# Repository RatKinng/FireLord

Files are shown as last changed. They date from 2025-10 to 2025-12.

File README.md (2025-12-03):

# FireLord Sensor Network Platform

FireLord is an open hardware reference for low-cost, peer-to-peer sensor meshes. The repository captures mechanical models, firmware helpers, PCB files, and planning artifacts produced during an Alaskan field concept so future teams can reuse or adapt the design.

---

## Intended Audience

- Municipal and resource agencies that need rapidly deployable sensor coverage.
- Community groups and educators building inexpensive environmental monitors.
- Integrators evaluating FireLord as a foundation for broader sensing programs.

---

## Repository Map

| Path | Contents |
| --- | --- |
| [`device-firmware/`](device-firmware/README.md) | Arduino-oriented helpers for sensor sampling and LoRa communication. |
| [`device-case/`](device-case/README.md) | 3D models, print notes, and assembly guidance for the field enclosure. |
| [`pcb-and-schematics/`](pcb-and-schematics/README.md) | KiCad project for the carrier board and custom footprints. |
| [`cosmos-firelord/`](cosmos-firelord/README.md) | OpenC3 COSMOS stack with the FireLord LoRa plugin, Docker compose, and bridge config for a base-station FireLord node over USB serial. |

---

## System Overview

1. **Field nodes** collect local sensor data, flag anomalies, and rebroadcast peer packets.  
2. **Base stations** are FireLord nodes flashed in base-station mode (no sensors, receive-only) that log every packet over USB serial and forward data when backhaul is available.  
3. **Optional cloud services** expose data to stakeholders or downstream tooling.

The mesh design keeps infrastructure light: any node can relay data, and a single active base station is sufficient.

---

## Quick Start

1. Review the operating targets below (range, duty cycle, enclosure limits) and adjust for your field conditions.  
2. Select components from the baseline bill of materials; plan on roughly $75 per node at 100-unit scale.  
3. Manufacture or print hardware following the subsystem READMEs.  
4. Load the firmware scaffold, confirm sensor and LoRa links, and tailor packet contents.  
5. Deploy nodes so each device reaches two peers or a base station, then validate end-to-end logging.

Use the risk guidance below while planning; the most common issues are supply delays, isolated nodes, and inadequate solar input.

---

## Operating Targets

- Peer-to-peer LoRa range: design for non-line-of-sight coverage of at least 500 m between nodes; verify in your terrain.  
- Reporting cadence: transmit sensor packets no less frequently than every 60 s unless power constraints dictate a longer interval.  
- Receive availability: keep the radio in a ready state to forward peer traffic continuously.  
- Data bandwidth: maintain ≥ 1.2 KB/s (9600 baud) for device-to-device links.  
- Power: average receive-ready draw ≤ 100 mW with duty-cycled heaters; energy storage provided by supercapacitors only.  
- Mechanical envelope: keep external dimensions within 200 mm per axis to fit the reference enclosure.  
- Environmental durability: target IP55 ingress protection and verified operation down to −30 °C for at least 30 min.  
- Radio spectrum: operate in the regional sub-GHz LoRa band (e.g., 902–928 MHz in North America) with a fixed-length header and byte-structured frame format.  
- Bill of materials: $75 per node is achievable at 100-unit quantities using the parts listed below.

---

## Deployment Notes

- **Topology**: Maintain overlapping coverage; document approved node spacing before field work.  
- **Placement**: Mount above snow or vegetation, shield cables from wildlife, and orient vents downward.  
- **Backhaul**: Configure the base station to cache indefinitely; cloud transfer is optional.  
- **Operations**: Schedule inspections ahead of seasonal activities (e.g., controlled burns or tourism peaks).

---

## Ground Operations (COSMOS)

- Use `cosmos-firelord/` to run OpenC3 COSMOS locally and view the `LORA` target. Update `.env` secrets before exposing ports beyond localhost.  
- Bridge a base-station FireLord node (USB serial) to COSMOS with the provided profile: `./openc3.sh cli bridge openc3-cosmos-lora/bridge.txt write_port_name=/dev/ttyACM0 baud_rate=115200 router_port=2950`. The plugin instance expects `host.docker.internal:2950`.  
- Base-station firmware emits `DATA <nodeId> <ver> <ts> <tempCx100> <humidity> <co2> <pressure> <voc> <smoke> <flags>` on every validated packet; COSMOS tooling can key off that stable line alongside the `[RX]` log. Nodes are TX-only; no COSMOS commands defined.  
- Container lifecycle: `./openc3.sh run` to start, `./openc3.sh stop` to halt; see `cosmos-firelord/README.md` for rebuild and reload steps.

---

## Hardware Snapshot

| Component | Key details | Mount style | Unit cost (USD, 2-unit qty) | Remarks |
| --- | --- | --- | --- | --- |
| [LoRa module (Reyax RYLR998)](https://www.digikey.com/en/products/detail/reyax/RYLR998/22078252) | 3.3 V P2P radio | Through-hole module | 16.90 | Ships on a carrier with 2.54 mm headers; can be socketed or wired directly without reflow. |
| [MCU (Seeeduino XIAO SAMD21)](https://www.digikey.com/en/products/detail/seeed-technology-co-ltd/102010328/11506471) | Arduino-compatible controller | Castellated SMD | 5.40 | Hand-solderable to the XIAO footprint; DIP adapters are available if you prefer header pins. |
| [CO₂/temp/humidity sensor (Sensirion SCD40)](https://www.digikey.com/en/products/detail/sensirion-ag/SCD40-D-R2/13684008) | I²C environmental sensing | LGA SMD | 17.95 | Use a breakout like the [SparkFun SEN-18360](https://www.sparkfun.com/products/18360) when avoiding reflow. |
| [CO sensor (MQ-7)](https://www.digikey.com/en/products/detail/olimex-ltd/SNS-MQ7/21662604) | Analog gas sensor | Through-hole | 5.65 | Duty-cycle the heater to save power. |
| [Pressure sensor (NXP MPL115A2)](https://www.digikey.com/en/products/detail/nxp-usa-inc/MPL115A2ST1/16538791) | I²C barometer | LGA SMD | 4.75 | Choose a breakout (Adafruit 992 or similar) if assembling without reflow. |
| [Smoke sensor (DFRobot SEN0570)](https://www.digikey.com/en/products/detail/dfrobot/SEN0570/24611153) | Analog particle indicator | Module w/2.54 mm header | 4.90 | Mount behind vent mesh. |
| [VOC sensor (DFRobot SEN0566)](https://www.digikey.com/en/products/detail/dfrobot/SEN0566/24611145) | Analog VOC indicator | Module w/2.54 mm header | 4.90 | Co-locate with smoke sensor. |
| [Supercapacitor (Tecate TPLH-2R7-800)](https://www.digikey.com/en/products/detail/tecate-group/TPLH-2R7-800PS35X71/21378858) | 2.7 V 800 F storage | Radial through-hole | 17.50 (each) | Use two in series with balancing. |
| [Base-station node (FireLord in BASE_STATION_MODE)](https://www.digikey.com/en/products/detail/seeed-technology-co-ltd/102010328/11506471) | USB-powered receive-only gateway | Onboard | 5.40 + radio | Same hardware as field nodes; flash with `BASE_STATION_MODE=true` and omit sensors. |
| [Solar panel (Seeed 1 W)](https://www.mouser.com/ProductDetail/Seeed-Studio/313070001) | 5 V nominal, 1 W | Leaded | 11.95 | Size array for local insolation. |
| [Connectors, cabling, misc.](https://www.amazon.com/100Pcs-Connector-Include-Female-Ph2-0mm/dp/B0DMW21LWS) | JST harnesses, fasteners | Through-hole / pre-crimped | ~10.00 | Include spare gaskets and glands. |

Estimated total: ≈ $75 per field node at 100-unit scale. Choosing breakout boards for the SMD-only sensors raises cost slightly but simplifies assembly when reflow is unavailable.

---

## Power Profile

- 283 mW: receive-ready state with high-draw sensors active.  
- 116 mW: duty-cycled average with smoke/VOC heaters at 5 % duty.  
- 600 mAh equivalent storage supports ~7 h at peak load and ~17 h at averaged load.

Adjust sampling cadence, heater duty cycles, or panel capacity to meet local endurance goals.

---

## Risk Summary

| Theme | Mitigation |
| --- | --- |
| Part delays | Order early, maintain alternates, record substitutions. |
| Node isolation | Pre-survey install sites, document minimum spacing, train field crews. |
| Power loss | Site panels in clear sun, inspect seasonally, log low-voltage events. |
| Sensor drift | Implement firmware sanity checks; schedule recalibration windows. |
| Base station downtime | Provide backup power and confirm local logging before field work. |

Document mitigations and revisit them seasonally to keep deployments stable.

---

## Extending the Platform

- Add routing intelligence, adaptive transmit power, or health beacons for larger meshes.  
- Integrate SMS, dashboard, or API publishing pipelines.  
- Incorporate soil probes, weather stations, or perimeter sensors.  
- Package sensor pods for quick swap service.  
- Expand packet signing or integrity checks for regulated deployments.

---

## Prototype Artifacts

- Work breakdowns and PERT charts outline the original build sequence.  
- Firmware helpers (`I2C_COMMS`, `UART_COMMS`) provide safe defaults for sensor and radio access.  
- Mechanical CAD documents enclosure iterations and tolerance tests.

Use these as reference when creating production-ready variants.

---

## System Characteristics

- **Operating profile**: LoRa P2P mesh at 915 MHz (example: SF7, 125 kHz BW, CR 4/5, 10 dBm) with receive-ready nodes and 60 s sampling. Packets are fixed-length (23 bytes payload + CRC32) with flag bits for outliers and a rolling CRC buffer to block duplicates.  
- **Performance targets**: ≥ 500 m NLOS hops, ≥ 1.2 KB/s link budget (9600 baud), IP55 enclosure, −30 °C for 30 min, and < 200 mm mechanical span. Power: 283 mW RX-ready with heaters on; ≈116 mW average at 5 % heater duty. 600 mAh-equivalent storage yields ~7 h peak or ~17 h average runtime. BOM ≈ $75 per node at 100-unit quantities.  
- **Radio and payload**: Example initialization uses `AT`, `AT+MODE=TEST`, `AT+TEST=RFCFG,…`, `AT+TEST=RXLRPKT`; `UART_COMMS::p2pTxHex` waits for `+TEST: TX DONE`. Payload layout mirrors `device-firmware/FireLordNode` suggestions (version, device ID, timestamp, temperature, humidity, CO₂, CO, pressure, smoke, VOC, flags, CRC32).  
- **Electronics**: KiCad carrier hosts a Seeeduino XIAO (I²C, UART, analog), Reyax/Wio-E5 radio, and connectors for SCD40, MPL115A2, MQ-7, smoke, and VOC sensors. Supercapacitor pads include balancing; test pads expose 3.3 V, ground, UART TX/RX, and reset. Footprints favor hand assembly; run ERC/DRC, then generate Gerbers and pick-and-place before fab.  
- **Firmware behavior**: Samples I²C sensors via `I2C_COMMS`, analog after heater warm-up, validates ranges, packages the frame, records CRC history, and transmits through `UART_COMMS`. Bench mode seeds data when sensors are absent. Power practices include MOSFET-controlled heaters, RTC/low-power sleep, and voltage checks to gate TX.  
- **Enclosure and assembly**: `device-case` contains Fusion 360, STEP, 3MF, and OpenSCAD sources. Print with PETG/ASA/PC, 0.2 mm layers, ≥ 3 perimeters, 20 % infill; gaskets in TPU or 2 mm silicone. Assembly sequence: seat gasket, mount PCB on M3 standoffs, route solar/antenna through glands with strain relief, close lid diagonally, add vent mesh. Use conformal coating and desiccant; vents should face down. Heat/flame resistance is not provided.  
- **Deployment and validation**: Maintain overlapping node coverage, mount above vegetation/snow, shield cables, and cache packets indefinitely at the base-station node on USB serial. Validation steps: pre/post I²C scans, `LoRaE5::ping()`, inspect TX/RX/FWD serial logs (including `DATA …`) for delivery, and record hop counts during field trials. Revisit risk mitigations seasonally (supply, isolation, power, sensor drift, base-station uptime).  
- **Extension paths**: OTA or signed updates, adaptive routing/TX power, cloud/API publishing, additional sensors (soil, weather, perimeter), antenna/housing variants, and SMA with controlled impedance for external antennas.

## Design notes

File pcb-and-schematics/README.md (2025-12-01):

# Electronics Design Guide

The KiCad project in this directory defines the sensor carrier board used by FireLord. It is suitable for small fabrication runs and straightforward to adapt for alternate sensors or power stages.

---

## Project Layout

```
Pressure_Sensor/
└── Pressure_Sensor_Board/
    ├── Pressure_Sensor_Board.kicad_pro
    ├── Pressure_Sensor_Board.kicad_sch
    ├── Pressure_Sensor_Board.kicad_pcb
    ├── PressureSensor.pretty/
    └── fp-lib-table
```

Open the `.kicad_pro` file in KiCad 7+. If footprints appear missing, point KiCad to the bundled `PressureSensor.pretty` library.

---

## Circuit Highlights

- Seeeduino XIAO header exposing I²C, UART, analog, and power rails.  
- JST or locking connectors for CO, smoke, VOC, and other sensor daughterboards.  
- SCD40 and MPL115A2 wired on a shared I²C bus with 400 kHz pull-ups.  
- Supercapacitor pads with balancing resistors and space for optional regulators.  
- Test pads for 3.3 V, ground, UART TX/RX, and reset.

Trace widths and component spacing were selected for easy hand assembly.

---

## Fabrication Workflow

1. Run ERC/DRC and resolve any violations.  
2. Generate Gerbers, drills, and pick-and-place files; archive each release (e.g., `fab/2025-03-RevA/`).  
3. Order 1.6 mm FR-4, 1 oz copper boards from your preferred supplier.  
4. Assemble SMD parts first, then supercapacitors and connectors.  
5. Verify I²C devices with the firmware scan and confirm LoRa UART signalling before enclosure install.

---

## Customization Notes

- Update footprints and BOM items when swapping sensors; confirm mechanical clearance against the enclosure model.  
- Replace the supercapacitor block with LiFePO₄ hardware if longer runtime is required.  
- Add extra headers for status LEDs, buttons, or expansion harnesses.  
- Introduce an SMA footprint with controlled impedance if you need external antennas.

Record every change with a new schematic and PCB revision.

---

## Footprint Library

`PressureSensor.pretty` contains enlarged pads for hand soldering. If you fork the design, duplicate the library and keep naming conventions (e.g., `FLD_SENSOR_*`) so scripts resolve correctly. Export 3D models as needed for enclosure fit checks.

---

## Additional Notes

- BOM reference: LoRa radio $16.90, Seeeduino $5.40, SCD40 $17.95, supercapacitors $17.50 each, remaining sensors $5–$10.  
- Environmental targets: IP55 enclosure, −30 °C survivability for 30 min, and a 200 mm maximum dimension to fit the printed housing.  
- Common risks: delayed component deliveries, insufficient node density, and inadequate solar exposure; plan mitigations during layout and procurement.

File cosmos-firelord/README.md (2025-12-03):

# FireLord COSMOS Stack

This folder packages a ready-to-run OpenC3 COSMOS instance for FireLord field testing. It mounts the FireLord LoRa plugin, exposes the COSMOS web UI locally, and includes a bridge profile for piping radio traffic from a base-station FireLord node (USB serial) into COSMOS tools.

## What's Here

- `compose.yaml` and `.env`: container stack and defaults pinned to OpenC3 6.9.2 in local mode. Update the secrets in `.env` before exposing beyond localhost.
- `openc3-cosmos-lora/`: plugin source plus the TCP bridge profile (`bridge.txt`) that relays a LoRa serial link into COSMOS.
- `plugins/DEFAULT/openc3-cosmos-lora/`: the packaged `openc3-cosmos-lora-1.0.0.gem` with an instance preconfigured for target `LORA` on `host.docker.internal:2950`.
- `openc3.sh` / `openc3.bat`: helper wrapper for running, stopping, and managing COSMOS containers.

## Quick Start (Local)

1) Install Docker with Compose and add your user to the Docker group (or run with sudo).  
2) From the repo root: `cd cosmos-firelord`  
3) Edit `.env` to rotate all placeholder passwords and adjust ports if 2900/2943 collide locally.  
4) Start COSMOS:  
   - macOS/Linux: `./openc3.sh run`  
   - Windows: `openc3.bat run`  
   Wait for the `openc3-init` container to finish, then open http://localhost:2900.

## Hook Up the Base-Station Node

The FireLord plugin expects a TCP feed on port `2950`. Use the included bridge profile to forward a FireLord device running `BASE_STATION_MODE=true` (receive-only, sensorless) into that port:

```bash
cd cosmos-firelord
./openc3.sh cli bridge openc3-cosmos-lora/bridge.txt \
  write_port_name=/dev/ttyACM0 \
  read_port_name=/dev/ttyACM0 \
  baud_rate=115200 \
  router_port=2950
```

- COSMOS “attempting to connect” here is only the TCP socket to this bridge, not RF link state. If you see it, the bridge is not reachable.
- Free the port first. `compose.yaml` currently maps `openc3-minio` to `127.0.0.1:2950`, which blocks the bridge. Comment that mapping or pick another port and update `plugin.txt`, `plugin_instance.json`, and `bridge.txt` to match.
- Run the bridge where the USB device is available. The helper command runs inside a container; on Windows/WSL it is often easier to run a host-side serial→TCP forwarder on the chosen port instead.

- Change `/dev/ttyACM0` to the COM/tty device for your base-station node.  
- Adjust `router_listen_address` if COSMOS is running on another host.  
- The plugin instance in `plugins/DEFAULT` points to `host.docker.internal:2950`, so the bridge must run on the same machine as Docker.

## Using the FireLord LORA Target

- Target name: `LORA` (configurable via `plugins/DEFAULT/openc3-cosmos-lora/plugin_instance.json`).  
- Interface: TCP client to the local bridge (port 2950).  
- Telemetry reflects the 23-byte FireLord sample payload (version, node ID, uptime seconds, temperature x100 C, humidity x100 %, CO2 ppm, pressure x10 hPa, VOC/SMOKE ADC counts, status flags, CRC32). The base-station firmware emits a `DATA …` line for every validated packet that can be parsed downstream; nodes are TX-only, so no commands are defined yet.  
- Screens/procedures live under `openc3-cosmos-lora/targets/LORA/` and will appear in COSMOS once the plugin is loaded.

## Updating the Plugin

1) Edit the plugin source under `openc3-cosmos-lora/` (e.g., add real telemetry items).  
2) Build a new gem: `./openc3.sh cli rake build VERSION=1.0.1` from inside `openc3-cosmos-lora/`.  
3) Replace the gem in `plugins/DEFAULT/openc3-cosmos-lora/` and update `plugin_instance.json` if the filename changes.  
4) Reload the plugin in COSMOS (Admin → Plugins) or via CLI:  
   `./openc3.sh cli load plugins/DEFAULT/openc3-cosmos-lora/openc3-cosmos-lora-1.0.1.gem DEFAULT plugins/DEFAULT/openc3-cosmos-lora/plugin_instance.json force`.

## Notes

- Keep the `.env` credentials private; they are mounted directly into containers.  
- The `plugins/DEFAULT` directory is bind-mounted and will be modified at runtime; commit only intentional changes.  
- For networks beyond localhost, enable TLS by swapping `openc3-traefik/traefik.yaml` for one of the SSL variants and providing certificates.

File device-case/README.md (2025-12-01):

# Device Enclosure Guide

This directory holds the enclosure CAD for the FireLord node. Models target desktop FDM printers and support IP55-style sealing.

---

## File Index

| File | Notes |
| --- | --- |
| `FireLordCase.f3d` | Fusion 360 source. |
| `FireLordCase.step` | Neutral CAD export. |
| `FireLordCase.3mf` | Full assembly print plate. |
| `FireLordCaseBody.*`, `FireLordCaseLid.*`, `FireLordCaseGasket.*` | Individual components. |
| `FireLordCaseMesh.*` | Vent cover for airflow. |
| `case.scad`, `size-tests.scad` | OpenSCAD parametric scripts and tolerance checks. |

---

## Print Defaults

- Material: PETG, ASA, PC, or other outdoor-tolerant material; PLA only for indoor pilots. Gasket should be TPU or other flexible filament.  
- Layer height: 0.2 mm (0.16 mm for smoother gasket lands).  
- Perimeters: ≥ 3 (for sufficient water-proofing).  
- Infill: 20 % grid/gyroid for the body; solid for the gasket supports.  
- Supports: Off for body/lid/gasket; trees for the mesh.  
- Orientation: Body upright, lid upside-down, mesh and gasket flat.

Run `size-tests.scad` before large batches.

---

## Assembly Steps

1. **Gasket** – Print in TPU or cut 2 mm silicone, then dry-fit the lid channel.  
2. **Electronics** – Mount the PCB on standoffs with stainless M3 hardware; align sensors with vent openings.  
3. **Cabling** – Route solar and antenna leads through side ports, sealing with glands or potting as required; strain-relief internal wiring.  
4. **Closure** – Seat the gasket, tighten lid screws diagonally, confirm even compression.  
5. **Finish** – Install the mesh cover and label the enclosure with device ID and install date.

---

## Environmental Notes

- **Cold**: Add insulating foam around supercapacitors and orient vents downward to shed ice.  
- **Moisture**: Apply conformal coating and include desiccant in humid regions.  
- **Wildlife**: Mount ≥ 3 m high where large animals are active; guard solar panels with metal frames.  
- **Heat or flame**: The case is not fire-rated—document safe-service guidelines for field teams.

---

## CAD Adjustments

- Modify `case.scad` for alternate sensor cut-outs or mounting features.  
- Extend the lid if an external antenna requires additional clearance.  
- Add hinged or quick-release hardware if frequent access is expected.

Track revisions alongside firmware changes to keep assemblies synchronized.

---

## Deployment Reminders

- Assemble indoors and transport with desiccant packs.  
- Use torque-limited drivers to prevent cracking.  
- Record install coordinates and photos.  
- Inspect critical sites before seasonal operations to clear vents and verify seals.

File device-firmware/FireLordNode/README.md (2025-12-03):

# Device Firmware Guide

The firmware runs on a Seeeduino XIAO SAMD21 (or comparable 3.3 V Arduino board) and drives the Reyax-class LoRa module plus the sensor suite. This outline assumes Arduino IDE or PlatformIO as the build tool.

---

## Inputs and Dependencies

- MCU: Seeeduino XIAO SAMD21 with hardware UART and I²C.  
- LoRa radio: Grove Wio-E5, Reyax RYLR998, or any AT-driven LoRa-E5 module on 3.3 V logic.  
- Sensors: SCD40 (I²C), MQ-7 (analog), MPL115A2 (I²C), MEMS smoke (analog), MEMS VOC (analog).  
- Host tooling: Arduino IDE or PlatformIO with Seeed SAMD board package.  
- Helpers: `I2C_COMMS`, `UART_COMMS`, and `SamplePacket.h`; optional `pseudo.cpp` shows an early loop.

---

## File Reference

| File | Purpose |
| --- | --- |
| `FireLordNode.ino` | Main sketch for the field node; samples sensors and forwards packets via LoRa-E5. |
| `I2C_COMMS.*` | Safe wrappers for register reads and raw bursts. |
| `UART_COMMS.*` | Stream helper with LoRa-E5 AT shortcuts. |
| `pseudo.cpp` | Example loop covering sampling, validation, and packet assembly. |

Import the sketch folder (`FireLordNode.ino`, helper headers, and sources) into Arduino IDE or PlatformIO as-is; avoid renaming the files because the build references them directly.

---

## Bring-Up Checklist

1. Install the “Seeed SAMD Boards” package in Arduino IDE (or PlatformIO equivalent).  
2. Create a project, add the helper headers, and include them in `setup()`.  
3. Wire sensors to SDA/SCL and analog inputs; connect the LoRa module to `Serial1`.  
4. Run an I²C scan and `LoRaE5::ping()` to confirm hardware connectivity.

---

## Sampling Pattern

Each node wakes every 30 s, samples local sensors, and packages readings into a fixed 23-byte payload plus a CRC32 footer. The CRC is stored in a small ring buffer so the node can recognise its own transmissions and recent relays. The high-level flow is:

1. Wake on a timer (e.g., 60 s).  
2. Read I²C sensors with `I2C::readFromReg`.  
3. Sample analog channels after heater warm-up.  
4. Validate ranges and set flag bits for outliers.  
5. Package values, record the CRC, and hand off for LoRa transmission.

Keep a short hash history to reject duplicate packets and duty-cycle heater loads to save power.

---

## Base Station Mode

- Set `BASE_STATION_MODE` to `true` in `FireLordNode.ino` to run the firmware as a USB-powered receive-only gateway with no sensors attached.  
- Sensor pin setup and I²C bring-up are skipped; the radio is still configured with `AT+MODE=TEST`, `AT+TEST=RFCFG,…`, and `AT+TEST=RXLRPKT`.  
- Every validated packet prints a stable machine-readable line:  
  `DATA <nodeId> <ver> <ts> <tempCx100> <humidity> <co2> <pressure> <voc> <smoke> <flags>`  
- No LoRa transmissions occur in this mode (uplinks and forwarding are bypassed). Use it for COSMOS ingest or host-side logging.

---

## LoRa Configuration

```cpp
UART_COMMS radio(Serial1);
radio.begin(9600);
LoRaE5::setMode(radio, 2); // P2P mode
LoRaE5::p2pConfig(radio, 915000000UL, 7, 125, 12, 10);
```

Configuration mirrors Seeed’s Wio-E5 examples: the firmware issues `AT`, `AT+MODE=TEST`, `AT+TEST=RFCFG,…`, and `AT+TEST=RXLRPKT` during boot. `UART_COMMS::p2pTxHex` waits for a `+TEST: TX DONE` response so the code knows if the send succeeded. A rolling set of CRCs prevents retransmitting the same payload again.

---

## Suggested Packet Layout

```
0   : Protocol version
1   : Device ID
2-7 : UNIX timestamp
8-9 : Temperature (°C ×100)
10-11: Humidity (% ×100)
12-13: CO₂ (ppm)
14-15: CO (ppm ×10)
16-17: Pressure (Pa offset)
18  : Smoke index (0-255)
19  : VOC index (0-255)
20  : Status flags
21-24: Packet hash (CRC32 or similar)
```

Stay below 51 bytes to remain compatible with common LoRa P2P settings.

---

## Power Practices

- Sleep between samples using an RTC alarm or LowPower helper.  
- Switch heater-powered sensors (smoke/VOC) with MOSFETs to keep the ≈116 mW average target.  
- Monitor the supply rail; defer transmissions if the supercapacitor droops.  
- Adjust `SAMPLE_INTERVAL_MS` if you need faster or slower updates.

Reference power budget: ~283 mW receive-ready with heaters on; ~116 mW with the default 5 % heater duty-cycle. Supercapacitors sized at 600 mAh-equivalent give ~7 h of autonomy without sun.

---

## Testing and Maintenance

- Bench test with sensors unplugged; the sketch falls back to seeded data and sets status flags when live sensors are missing.  
- Watch serial logs: `[TX] payload=…` marks transmissions, `[RX] …` shows decoded inbound packets, `[FWD] …` indicates a relayed frame, and `DATA …` is emitted for every validated packet (even in base-station mode).  
- Tag firmware releases that go to the field and keep binaries for rollback.  
- The built-in LED flashes after each successful transmit; no blink means the LoRa handshake failed.

---

## Possible Extensions

- Add OTA update hooks or signed firmware if tamper evidence is required.  
- Tie into alternate transports (Bluetooth provisioning, Wi-Fi debug bridges).  
- Enable additional sensors or derived metrics (AQI, fuel moisture indices).  
- Expand the CRC cache size or persist hashes if your mesh needs longer duplicate suppression windows.  
- Publish maintenance telemetry (uptime, duty cycle stats, supply voltage minima).

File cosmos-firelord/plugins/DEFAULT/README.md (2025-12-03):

# Default Scope Contents

This scope is mounted by the COSMOS containers to hold installed plugins and any runtime edits made through the UI. It currently contains the FireLord LoRa plugin instance:

- `openc3-cosmos-lora/`: prebuilt `openc3-cosmos-lora-1.0.0.gem` plus `plugin_instance.json` that maps target `LORA` to `host.docker.internal:2950`.

Treat this folder as configuration-controlled storage. After running COSMOS, additional files may appear here; commit only the intentional plugin changes.

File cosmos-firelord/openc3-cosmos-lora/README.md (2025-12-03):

# FireLord LoRa COSMOS Plugin

This plugin packages the FireLord LoRa target for OpenC3 COSMOS. It ships with a TCP client interface that expects a host-side bridge from a FireLord base-station node (USB serial) and includes stub command/telemetry definitions you can replace with the real packet map.

## Structure

- `plugin.txt`: declares target `LORA` and a TCP client pointed at `host.docker.internal:2950`. The value for `lora_target_name` is templated so it can be overridden when loading the plugin.  
- `bridge.txt`: host-side serial↔TCP bridge. Run it on the same machine as Docker so the container can reach `host.docker.internal:2950`.  
- `targets/LORA/`: placeholder COSMOS target (cmd/tlm, screens, procedures, and a helper `lib/lora.py`). Swap these with real items to visualize FireLord traffic.
- `openc3-cosmos-lora-1.0.0.gem`: prebuilt gem consumed by `plugins/DEFAULT/openc3-cosmos-lora/plugin_instance.json`.

## Running the Bridge

From the `cosmos-firelord` directory:

```bash
./openc3.sh cli bridge openc3-cosmos-lora/bridge.txt \
  write_port_name=/dev/ttyACM0 \
  read_port_name=/dev/ttyACM0 \
  baud_rate=115200 \
  router_port=2950
```

- COSMOS “attempting to connect” is only the TCP socket to this bridge, not RF link state. If you see that message, the bridge is unreachable.
- Ensure the port is free. In this stack `compose.yaml` maps `openc3-minio` to `127.0.0.1:2950`; comment that mapping or pick a new port and update `plugin.txt`, `plugin_instance.json`, and `bridge.txt` together.
- Run the bridge where the base-station device (FireLord node with `BASE_STATION_MODE=true`) is accessible over USB serial. The helper command runs in a container; on Windows/WSL you may need a host-side serial→TCP forwarder listening on the chosen port instead.

- Match the `router_port` to `plugin.txt` (2950 by default).  
- Update `write_port_name`/`read_port_name` for your COM/tty device and parity/flow control if needed; the base-station firmware uses 115200 baud.  
- Set `router_listen_address=0.0.0.0` only when COSMOS runs on another host and you trust the network.

## Editing and Rebuilding

1) Update the target definitions under `targets/LORA/` and any supporting utilities.  
2) Bump the gem version and rebuild from this folder:  
   `./openc3.sh cli rake build VERSION=1.0.1`  
3) Copy the new gem into `plugins/DEFAULT/openc3-cosmos-lora/` and update `plugin_instance.json` so COSMOS loads the new filename.  
4) Reload the plugin through the COSMOS Admin > Plugins page or `./openc3.sh cli load ...` (see `cosmos-firelord/README.md`).

General, upstream plugin boilerplate now lives in `README.upstream.md` for reference.

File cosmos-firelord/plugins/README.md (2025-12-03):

# Plugins Volume (FireLord)

This directory is bind-mounted into COSMOS so plugin gems and instance metadata persist across container restarts. For FireLord we keep the LoRa plugin preloaded here so a fresh `./openc3.sh run` comes up with the `LORA` target available.

- `DEFAULT/`: default COSMOS scope. Runtime writes here, so expect timestamps or cache files after COSMOS runs.  
- `DEFAULT/openc3-cosmos-lora/`: packaged `openc3-cosmos-lora` gem and its `plugin_instance.json`, which points to `host.docker.internal:2950` for LoRa traffic.

If you rebuild the plugin, replace the gem in `DEFAULT/openc3-cosmos-lora/` and reload via the COSMOS Admin UI or `./openc3.sh cli load ...` (see `cosmos-firelord/README.md`). Keep `README.upstream.md` for the original OpenC3 guidance.

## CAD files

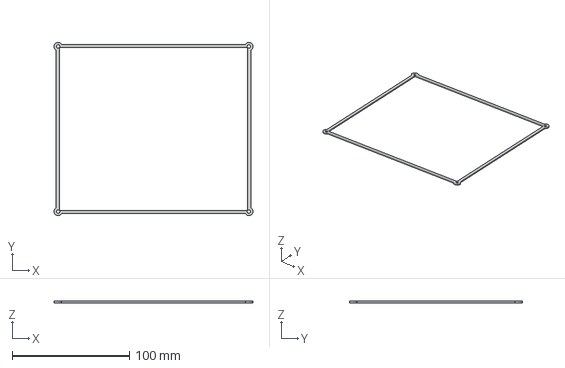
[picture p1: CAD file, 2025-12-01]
device-case/FireLordCaseGasket.step
169.9 x 147.9 x 1.40 mm

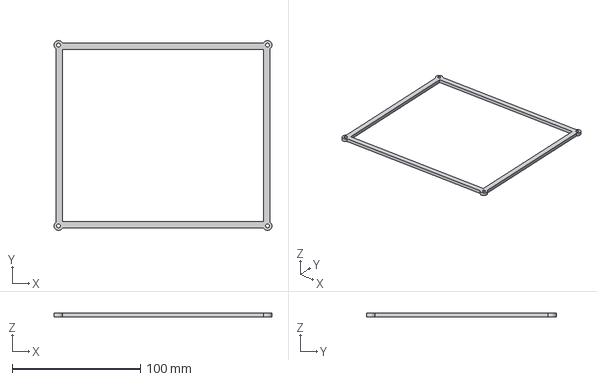
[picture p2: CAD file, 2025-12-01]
device-case/FireLordCase.step
169.9 x 147.9 x 3.00 mm

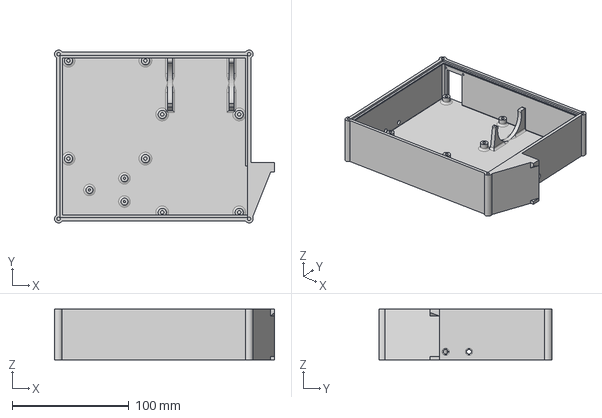
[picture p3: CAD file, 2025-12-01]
device-case/FireLordCaseBody.step
188.1 x 147.9 x 43.5 mm

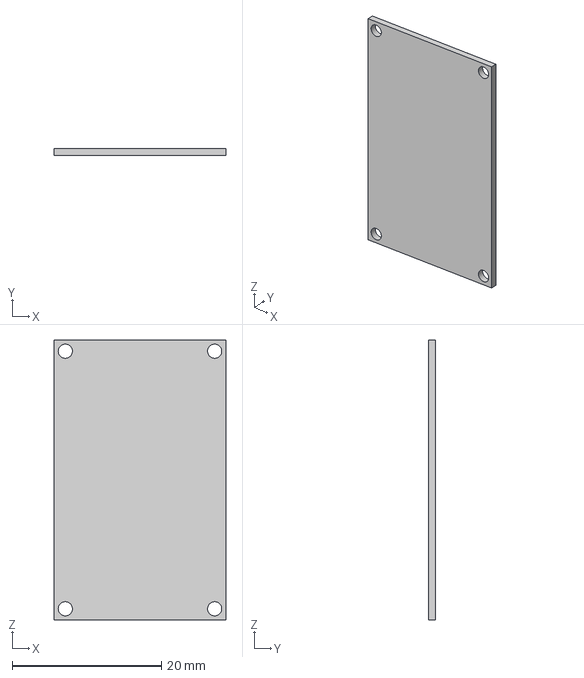
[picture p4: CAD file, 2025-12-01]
device-case/FireLordCaseMesh.step
23.0 x 1.00 x 37.5 mm

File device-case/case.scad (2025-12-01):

// FireLord Device Case

$fn = 32;

solar_panel_len = 160.4;
solar_panel_wid = 138.4;
solar_panel_h = 2.7;

perfboard_len = 90.4;
perfboard_wid = 70.4;
perfboard_thick = 1.6;
perfboard_leeway = 6.0; // spacing under the board
perfboard_hole_dia = 3.0;
// inset distances from each perboard corner
perfboard_hole_corner_x = 1.8+perfboard_hole_dia/2;
perfboard_hole_corner_y = 0.8+perfboard_hole_dia/2;

supercap_dia = 36.1;
supercap_len = 73.3;

lora_screw_shaft_dia = 1.9;
lora_screw_shaft_len = 6.1;
lora_screw_head_dia = 4.0;
lora_screw_head_len = 2.1;
// The LoRa module has three mounting holes in an
// isosceles triangle layout (if they're your vertices)
// These are the holes closest together (the base)
lora_hole_tria_base = 21.8-lora_screw_shaft_dia; // From far hole edge to far hole edge; -dia makes centered.
lora_hole_tria_h = 29.0+lora_screw_shaft_dia/2;
lora_antenna_hole_dia = 2.0;
// Offsets from top-most mount hole to antenna hole
lora_antenna_h_offset_x = -3.7;
lora_antenna_h_offset_y = -2.6;

wall_thick = 1.6;

supercap_clip_h = supercap_dia/6; // How far the clipping portion extends
cap_clip_rounding = 0.7;
cap_clip_section_thick = 4.0;

case_rounding = 4.0;

case_screw_dia = 3.0;

module loraScrewHole2D() {
    circle(d=lora_screw_shaft_dia);
}

module loraScrewHoles2D() {
    translate([-lora_hole_tria_base/2,0])
    circle(d=lora_screw_shaft_dia);
    translate([lora_hole_tria_base/2,0])
    circle(d=lora_screw_shaft_dia);
    translate([0,lora_hole_tria_h]) {
        circle(d=lora_screw_shaft_dia);
        //translate([lora_antenna_h_offset_x,lora_antenna_h_offset_y])
        //circle(d=lora_antenna_hole_dia);
    }
}

module perfboardHole2D() {
    circle(d=perfboard_hole_dia);
}

module perfboardHoles2D() {
    x_val = perfboard_len/2-perfboard_hole_corner_x;
    y_val = perfboard_wid/2-perfboard_hole_corner_y;

    translate([x_val, y_val])
    perfboardHole2D();
    translate([-x_val, y_val])
    perfboardHole2D();
    translate([x_val, -y_val])
    perfboardHole2D();
    translate([-x_val, -y_val])
    perfboardHole2D();
}
//perfboardHoles2D();

module capacitor2D() {
    circle(d=supercap_dia);
}

module capacitorClipDiff2D() {
    difference() {
        capacitor2D();
        translate([0,supercap_dia/2+supercap_clip_h])
        square(supercap_dia, center=true);
    }
}
//capacitorClipDiff2D();

// Side profile
module capacitorClipCircle2D() {
    difference() {
        offset(wall_thick)
        capacitorClipDiff2D();
        translate([0,supercap_dia/2+supercap_clip_h])
        square([supercap_dia+wall_thick*2, supercap_dia], center=true);
    }
}
//capacitorClipCircle2D();

module capacitorClip2D() {
    offset(cap_clip_rounding) offset(-cap_clip_rounding)
    difference() {
        hull() {
            capacitorClipCircle2D();
            translate([0,-supercap_dia/4+supercap_clip_h/2])
            square([supercap_dia+3*wall_thick, supercap_dia/2+supercap_clip_h+wall_thick*2], center=true);
        }
        capacitor2D();
    }
    translate([0,cap_clip_rounding/2-supercap_dia/2-wall_thick])
    square([supercap_dia+3*wall_thick, cap_clip_rounding], center=true);
}
//capacitorClip2D();
// Test translate of the screw hole
//translate([supercap_dia/2+perfboard_hole_dia/2+wall_thick,0])
//#square([perfboard_hole_dia, 10], center=true);

module capacitorClipSection3D() {
    translate([0,cap_clip_section_thick/2,supercap_dia/2])
    rotate([90,0,0])
    linear_extrude(cap_clip_section_thick)
    capacitorClip2D();
}
capacitorClipSection3D();

//module caseScrewHoles

module caseBodyHollow() {
    difference() {
        linear_extrude(supercap_dia*2)
        offset(case_rounding) offset(-case_rounding)
        square([solar_panel_len+4*wall_thick+2*case_screw_dia, solar_panel_wid+4*wall_thick+2*case_screw_dia], center=true);
        translate([0,0,wall_thick])
        linear_extrude(supercap_dia*2-wall_thick)
        offset(case_rounding) offset(-case_rounding)
        square([solar_panel_len, solar_panel_wid], center=true);
    }
}

//caseBodyHollow();

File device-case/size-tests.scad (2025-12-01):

// FireLord Device Case

use <case.scad>;


$fn = 32;

module holeTestifyHelper() {
    difference() {
        offset(1.6)
        hull() {
            children();
        }
        children();
    }
}

module holeTestify() {
    linear_extrude(1.0)
    difference() {
        holeTestifyHelper() children();
        
        offset(1.6) offset(-1.6*2)
        holeTestifyHelper() children();
    }
}

// To be printed in vase mode
module capacitorTest3D() {
    linear_extrude(73.3+0.4)
    offset(0.4)
    capacitor2D();
    
    
}
//capacitorTest3D();

// Small prints to test if the hole spacing/sizes are correct
//holeTestify() loraScrewHoles2D();
holeTestify() perfboardHoles2D();

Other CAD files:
device-case/FireLordCaseLid.step
device-case/FireLordCase.3mf
device-case/FireLordCase.f3d
device-case/FireLordCaseBody.3mf
device-case/FireLordCaseGasket.3mf
device-case/FireLordCaseLid.3mf
device-case/FireLordCaseMesh.3mf

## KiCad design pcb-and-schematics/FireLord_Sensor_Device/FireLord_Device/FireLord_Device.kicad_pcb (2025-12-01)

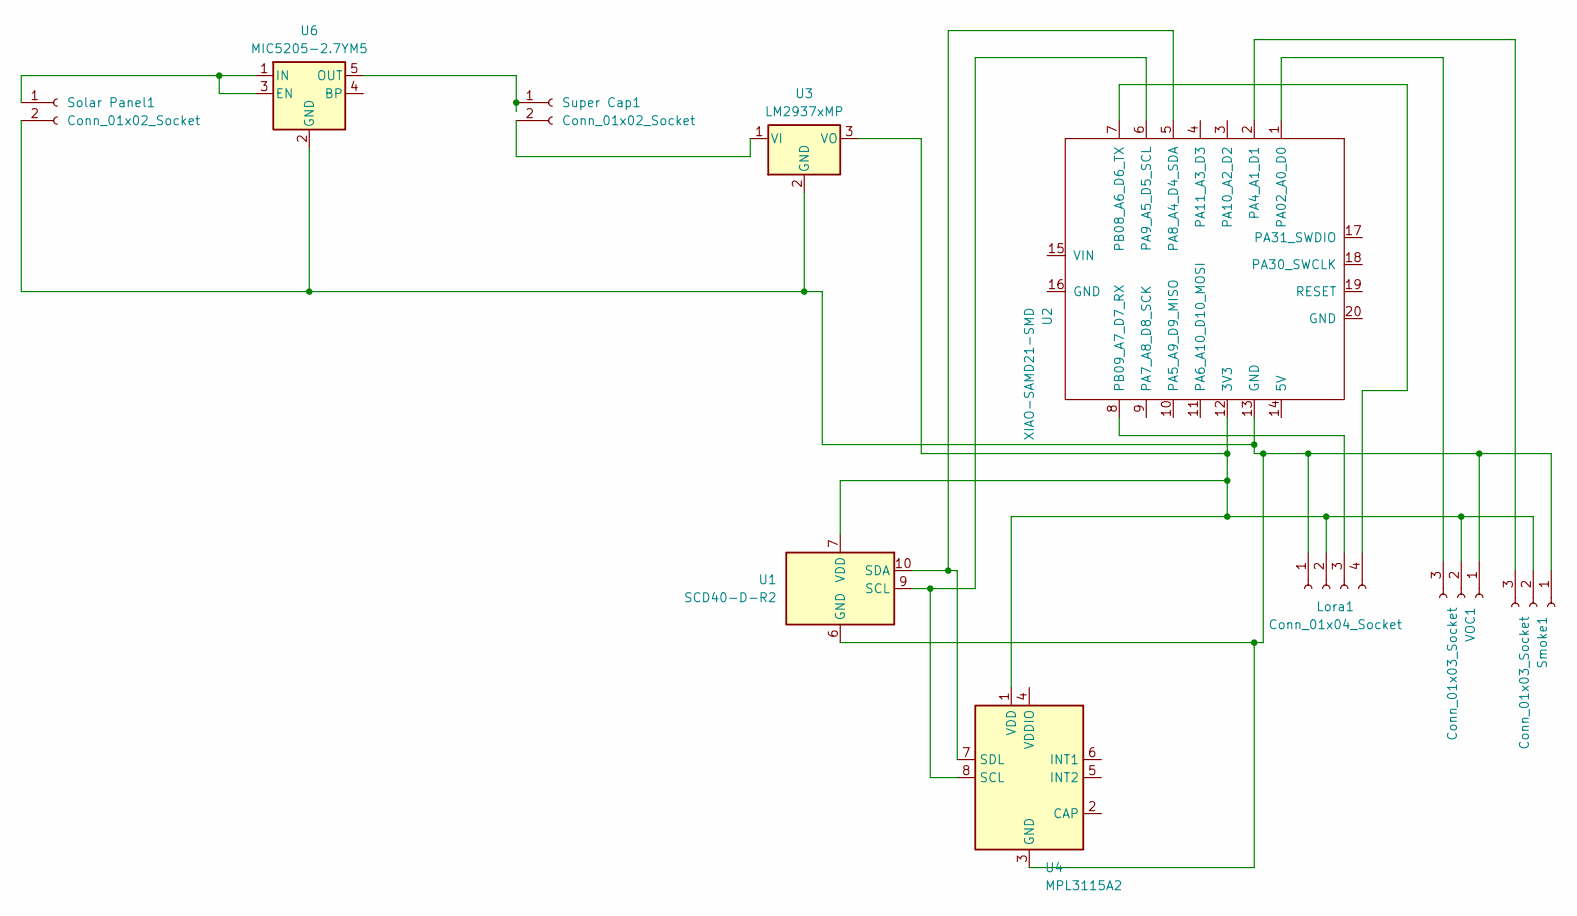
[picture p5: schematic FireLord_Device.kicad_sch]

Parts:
Lora1: Conn_01x04_Socket; JST_EH_B4B-EH-A_1x04_P2.50mm_Vertical
Smoke1: Conn_01x03_Socket; FanPinHeader_1x03_P2.54mm_Vertical
Solar Panel1: Conn_01x02_Socket; JST_XA_B02B-XASK-1-A_1x02_P2.50mm_Vertical
Super Cap1: Conn_01x02_Socket; JST_XA_B02B-XASK-1-A_1x02_P2.50mm_Vertical
U1: SCD40-D-R2; Sensirion_SCD4x-1EP_10.1x10.1mm_P1.25mm_EP4.8x4.8mm
U2: XIAO-SAMD21-SMD
U3: LM2937xMP; SOT-223-3_TabPin2
U4: MPL3115A2; NXP_LGA-8_3x5mm_P1.25mm_H1.1mm
U6: MIC5205-2.7YM5; SOT-23-5
VOC1: Conn_01x03_Socket; FanPinHeader_1x03_P2.54mm_Vertical

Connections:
unnamed: Lora1.1, Smoke1.1, Solar Panel1.2, U1.6 (GND), U1.20 (GND), U1.21 (GND), U2.13 (GND), U3.2 (GND), U4.3 (GND), U6.2 (GND), VOC1.1
unnamed: Lora1.2, Smoke1.2, U1.7 (VDD), U1.19 (VDD), U2.12 (3V3), U3.3 (VO), U4.1 (VDD), VOC1.2
unnamed: Lora1.3, U2.8 (PB09_A7_D7_RX)
unnamed: Lora1.4, U2.7 (PB08_A6_D6_TX)
unnamed: Smoke1.3, U2.2 (PA4_A1_D1)
unnamed: Solar Panel1.1, U6.1 (IN), U6.3 (EN)
unnamed: Super Cap1.1, U6.5 (OUT)
unnamed: Super Cap1.2, U3.1 (VI)
unnamed: U1.9 (SCL), U2.6 (PA9_A5_D5_SCL), U4.8 (SCL)
unnamed: U1.10 (SDA), U2.5 (PA8_A4_D4_SDA), U4.7 (SDL)
unnamed: U2.1 (PA02_A0_D0), VOC1.3

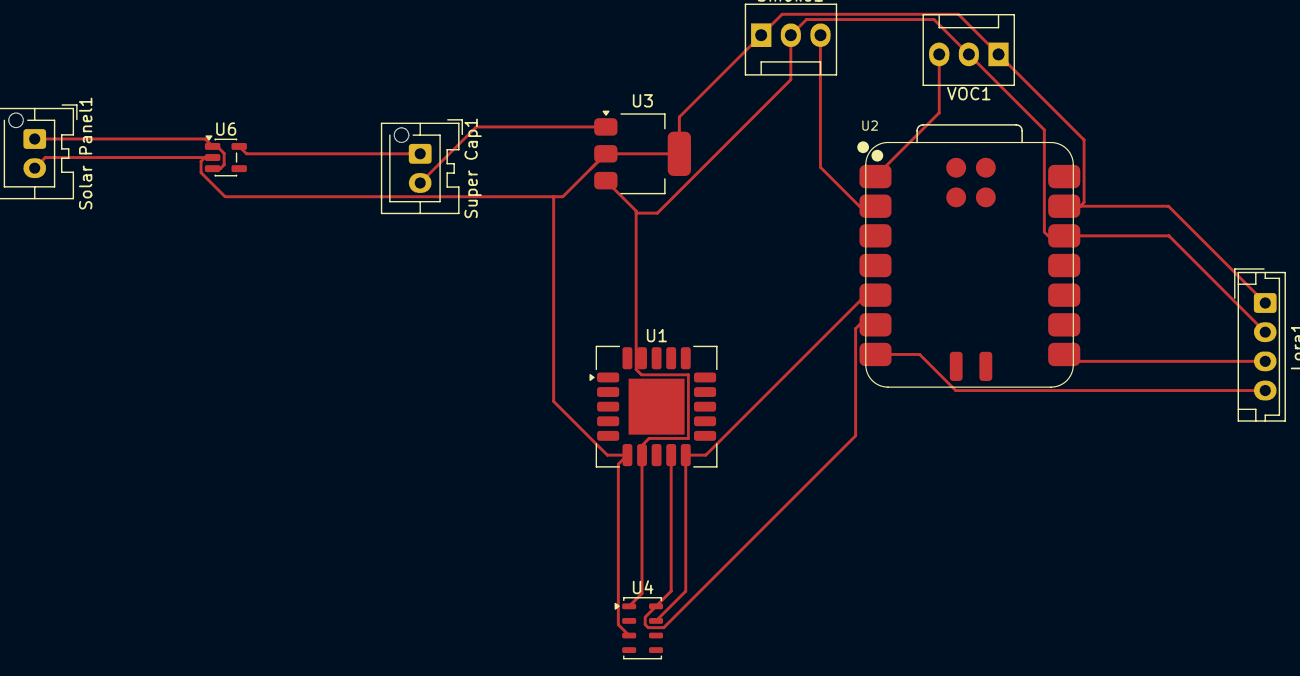
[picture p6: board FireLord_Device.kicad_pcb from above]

Board: 2 copper layers, 10 parts (0 on the bottom side), 11 nets.

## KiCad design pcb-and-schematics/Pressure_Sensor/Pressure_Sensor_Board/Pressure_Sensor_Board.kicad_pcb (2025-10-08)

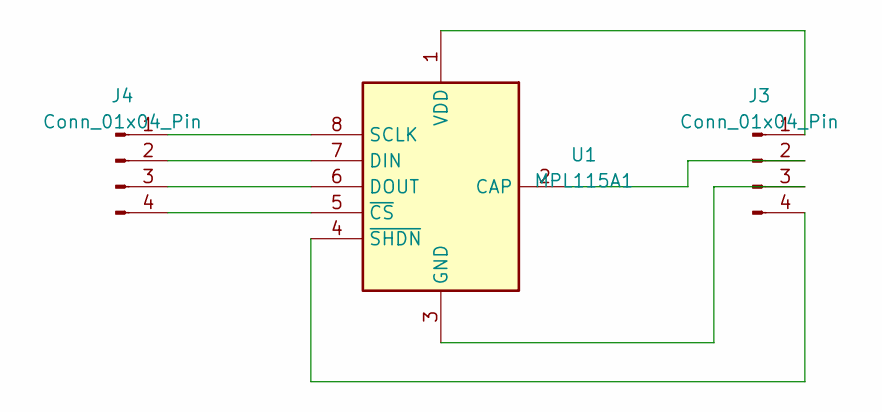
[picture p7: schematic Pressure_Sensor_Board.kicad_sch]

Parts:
J3, J4: Conn_01x04_Pin; PinHeader_1x04_P1.27mm_Vertical
U1: MPL115A1; NXP_LGA-8_3x5mm_P1.25mm_H1.2mm

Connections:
unnamed: J3.1, U1.1 (VDD)
unnamed: J3.2, U1.2 (CAP)
unnamed: J3.3, U1.3 (GND)
unnamed: J3.4, U1.4 (~SHDN)
unnamed: J4.1, U1.8 (SCLK)
unnamed: J4.2, U1.7 (DIN)
unnamed: J4.3, U1.6 (DOUT)
unnamed: J4.4, U1.5 (~CS)

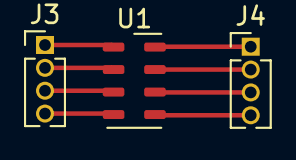
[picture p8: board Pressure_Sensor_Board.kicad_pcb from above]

Board: 2 copper layers, 3 parts (0 on the bottom side), 8 nets.

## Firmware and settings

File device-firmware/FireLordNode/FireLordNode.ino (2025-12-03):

#include <Arduino.h>
#include "I2C_COMMS.h"
#include "UART_COMMS.h"
#include "SamplePacket.h"

constexpr bool LORA_DEBUG      = false;
constexpr bool BASE_STATION_MODE = false;  // set false for normal sensor/uplink node

// ----- Configuration -------------------------------------------------------

constexpr uint8_t DEVICE_ID            = 1;
constexpr uint32_t SAMPLE_INTERVAL_MS  = 30000;   // 30 seconds between uplinks
constexpr uint32_t LORA_FREQUENCY_HZ   = 915000000UL;
//constexpr uint32_t LORA_FREQUENCY_HZ = 915125000UL;
constexpr int      LORA_SPREADING_FACT = 7;
constexpr int      LORA_BW_KHZ         = 125;
constexpr int      LORA_PREAMBLE_LEN   = 12;
constexpr int      LORA_TX_POWER_DBM   = 10;

constexpr uint8_t VOC_PIN              = A0;       // D0
constexpr uint8_t SMOKE_PIN            = A1;       // D1

// ----- Sensor state --------------------------------------------------------

namespace {

// Sensirion SCD40 (CO₂, temperature, humidity)
constexpr uint8_t SCD40_ADDR = 0x62;
bool scd40Active = false;

// NXP MPL115A2 (pressure)
constexpr uint8_t MPL115A2_ADDR = 0x60;
bool mpl115a2Active = false;
float mplA0 = 0.0f;
float mplB1 = 0.0f;
float mplB2 = 0.0f;
float mplC12 = 0.0f;

UART_COMMS radio(Serial1, &Serial1);
bool loraReady = false;

} // namespace

// Track recently seen packet CRCs to avoid rebroadcast loops
static uint32_t recentCrcs[8] = {0};
static size_t recentCrcIndex = 0;

static bool hasSeenCrc(uint32_t crc) {
  for (uint32_t stored : recentCrcs) {
    if (stored == crc) return true;
  }
  return false;
}

static void rememberCrc(uint32_t crc) {
  recentCrcs[recentCrcIndex] = crc;
  recentCrcIndex = (recentCrcIndex + 1) % (sizeof(recentCrcs) / sizeof(recentCrcs[0]));
}

// ----- Utility -------------------------------------------------------------

static uint32_t crc32(const uint8_t *data, size_t len) {
  uint32_t crc = 0xFFFFFFFF;
  for (size_t i = 0; i < len; ++i) {
    uint8_t byte = data[i];
    crc ^= byte;
    for (int k = 0; k < 8; ++k) {
      uint32_t mask = -(crc & 1);
      crc = (crc >> 1) ^ (0xEDB88320 & mask);
    }
  }
  return ~crc;
}

static void encodeU16BE(uint8_t *dst, uint16_t value) {
  dst[0] = static_cast<uint8_t>((value >> 8) & 0xFF);
  dst[1] = static_cast<uint8_t>(value & 0xFF);
}

static void encodeS16BE(uint8_t *dst, int16_t value) {
  encodeU16BE(dst, static_cast<uint16_t>(value));
}

static void encodeU32BE(uint8_t *dst, uint32_t value) {
  dst[0] = static_cast<uint8_t>((value >> 24) & 0xFF);
  dst[1] = static_cast<uint8_t>((value >> 16) & 0xFF);
  dst[2] = static_cast<uint8_t>((value >> 8) & 0xFF);
  dst[3] = static_cast<uint8_t>(value & 0xFF);
}

static String toHex(const uint8_t *buf, size_t len) {
  static const char hex[] = "0123456789ABCDEF";
  String out;
  out.reserve(len * 2);
  for (size_t i = 0; i < len; ++i) {
    out += hex[(buf[i] >> 4) & 0x0F];
    out += hex[buf[i] & 0x0F];
  }
  return out;
}

static int hexNibble(char c) {
  if (c >= '0' && c <= '9') return c - '0';
  if (c >= 'A' && c <= 'F') return 10 + (c - 'A');
  if (c >= 'a' && c <= 'f') return 10 + (c - 'a');
  return -1;
}

static bool decodeHex(const String &hex, uint8_t *out, size_t maxLen, size_t &decodedLen) {
  size_t len = hex.length();
  if (len % 2 != 0) return false;
  size_t count = len / 2;
  if (count > maxLen) return false;
  for (size_t i = 0; i < count; ++i) {
    int hi = hexNibble(hex[i * 2]);
    int lo = hexNibble(hex[i * 2 + 1]);
    if (hi < 0 || lo < 0) return false;
    out[i] = static_cast<uint8_t>((hi << 4) | lo);
  }
  decodedLen = count;
  return true;
}

static bool sendATDebug(const String &cmd, const char *expect, uint32_t timeout_ms) {
  radio.flushInput();
  if (LORA_DEBUG) {
    Serial.print(F("[LoRa] -> "));
    Serial.println(cmd);
  }
  Serial1.print(cmd);
  if (!cmd.endsWith("\r\n")) {
    Serial1.print("\r\n");
  }

  String resp;
  uint32_t start = millis();
  while (millis() - start < timeout_ms) {
    while (Serial1.available()) {
      char c = (char)Serial1.read();
      resp += c;
    }
    if (resp.indexOf(expect) >= 0) {
      if (LORA_DEBUG) {
        Serial.print(F("[LoRa] <- "));
        Serial.println(resp);
      }
      return true;
    }
  }
  Serial.print(F("[LoRa] timeout waiting for "));
  Serial.print(expect);
  Serial.print(F(", got: "));
  Serial.println(resp);
  return false;
}

// ----- SCD40 helpers -------------------------------------------------------

static bool scd40StartPeriodicMeasurement() {
  const uint8_t cmd[] = {0x21, 0xB1};
  return I2C::writeBytes(SCD40_ADDR, cmd, sizeof(cmd));
}

static uint8_t scd40CRC(const uint8_t *bytes) {
  uint8_t crc = 0xFF;
  for (int i = 0; i < 2; ++i) {
    crc ^= bytes[i];
    for (int b = 0; b < 8; ++b) {
      if (crc & 0x80) {
        crc = (crc << 1) ^ 0x31;
      } else {
        crc <<= 1;
      }
    }
  }
  return crc;
}

static bool scd40Read(float &temperatureC, float &humidityPct, uint16_t &co2ppm) {
  if (!scd40Active) return false;

  const uint8_t cmd[] = {0xEC, 0x05};
  if (!I2C::writeBytes(SCD40_ADDR, cmd, sizeof(cmd))) {
    return false;
  }
  delay(5);

  uint8_t raw[9] = {0};
  if (!I2C::readRaw(SCD40_ADDR, raw, sizeof(raw))) {
    return false;
  }

  for (int i = 0; i < 3; ++i) {
    const uint8_t *chunk = &raw[i * 3];
    uint8_t crc = scd40CRC(chunk);
    if (crc != chunk[2]) {
      return false;
    }
  }

  uint16_t co2 = (static_cast<uint16_t>(raw[0]) << 8) | raw[1];
  uint16_t tempRaw = (static_cast<uint16_t>(raw[3]) << 8) | raw[4];
  uint16_t humRaw = (static_cast<uint16_t>(raw[6]) << 8) | raw[7];

  co2ppm = co2;
  temperatureC = -45.0f + 175.0f * (static_cast<float>(tempRaw) / 65535.0f);
  humidityPct = 100.0f * (static_cast<float>(humRaw) / 65535.0f);
  return true;
}

// ----- MPL115A2 helpers ----------------------------------------------------

static bool mpl115a2ReadCoefficients() {
  uint8_t buf[8] = {};
  if (!I2C::readFromReg(MPL115A2_ADDR, 0x04, buf, sizeof(buf))) {
    return false;
  }

  int16_t a0 = (static_cast<int16_t>(buf[0]) << 8) | buf[1];
  int16_t b1 = (static_cast<int16_t>(buf[2]) << 8) | buf[3];
  int16_t b2 = (static_cast<int16_t>(buf[4]) << 8) | buf[5];
  int16_t c12 = ((static_cast<int16_t>(buf[6]) << 8) | buf[7]) >> 2;

  mplA0  = static_cast<float>(a0) / 8.0f;
  mplB1  = static_cast<float>(b1) / 8192.0f;
  mplB2  = static_cast<float>(b2) / 16384.0f;
  mplC12 = static_cast<float>(c12) / 4194304.0f;
  return true;
}

static bool mpl115a2Read(float &pressureKPa) {
  if (!mpl115a2Active) return false;

  const uint8_t startConversion[] = {0x12, 0x00};
  if (!I2C::writeBytes(MPL115A2_ADDR, startConversion, sizeof(startConversion))) {
    return false;
  }
  delay(5);

  uint8_t data[4] = {};
  if (!I2C::readFromReg(MPL115A2_ADDR, 0x00, data, sizeof(data))) {
    return false;
  }

  uint16_t padc = ((static_cast<uint16_t>(data[0]) << 8) | data[1]) >> 6;
  uint16_t tadc = ((static_cast<uint16_t>(data[2]) << 8) | data[3]) >> 6;

  float pComp = mplA0 + (mplB1 + mplC12 * tadc) * padc + mplB2 * tadc;
  pressureKPa = pComp * 0.004f + 0.095f;
  return true;
}

// ----- Sensor orchestration ------------------------------------------------

static void sensorsBegin() {
  scd40Active = scd40StartPeriodicMeasurement();
  mpl115a2Active = mpl115a2ReadCoefficients();
}

static Sample collectSample(uint32_t nowMs) {
  Sample sample{};
  sample.timestamp = nowMs / 1000U;

  float temperatureC = 0.0f;
  float humidityPct = 0.0f;
  uint16_t co2ppm = 0;
  bool ambientOk = scd40Read(temperatureC, humidityPct, co2ppm);

  if (!ambientOk) {
    temperatureC = 21.5f;
    humidityPct = 45.0f;
    co2ppm = 415;
  } else {
    sample.statusFlags |= 0x01;
  }

  float pressureKPa = 0.0f;
  bool pressureOk = mpl115a2Read(pressureKPa);
  if (!pressureOk) {
    pressureKPa = 101.3f;
  } else {
    sample.statusFlags |= 0x02;
  }

  sample.temperatureCx100 = static_cast<int16_t>(temperatureC * 100.0f);
  sample.humidityPctx100  = static_cast<uint16_t>(humidityPct * 100.0f);
  sample.co2ppm           = co2ppm;
  sample.pressureDeciHpa  = static_cast<uint16_t>(pressureKPa * 100.0f); // kPa -> hPa*10

  sample.vocRaw   = analogRead(VOC_PIN);
  sample.smokeRaw = analogRead(SMOKE_PIN);

  if (sample.vocRaw >= 4090 || sample.smokeRaw >= 4090) {
    sample.statusFlags |= 0x04;
  }

  return sample;
}

// ----- LoRa helpers --------------------------------------------------------

static bool configureLoRa() {
  if (LORA_DEBUG) Serial.println(F("[LoRa] configuring radio..."));
  if (!sendATDebug(String(F("AT")), "+AT: OK", 1000)) {
    Serial.println(F("[LoRa] unable to reach module"));
    return false;
  }
  delay(200);
  if (!sendATDebug(String(F("AT+MODE=TEST")), "+MODE: TEST", 1000)) {
    Serial.println(F("[LoRa] failed to enter test mode"));
    return false;
  }
  delay(200);
  int freqMHz = static_cast<int>(LORA_FREQUENCY_HZ / 1000000UL);
  String cfg = String("AT+TEST=RFCFG,") + String(freqMHz) + ",SF" + String(LORA_SPREADING_FACT) + "," + String(LORA_BW_KHZ) + "," + String(LORA_PREAMBLE_LEN) + ",15," + String(LORA_TX_POWER_DBM) + ",ON,OFF,OFF";
  if (!sendATDebug(cfg, "+TEST: RFCFG", 1000)) {
    Serial.println(F("[LoRa] RFCFG command failed"));
    return false;
  }
  delay(200);
  sendATDebug(String(F("AT+TEST=RXLRPKT")), "+TEST: RXLRPKT", 500);
  if (LORA_DEBUG) Serial.println(F("[LoRa] configuration OK"));
  return true;
}

static uint32_t buildPacket(const Sample &sample, uint8_t *out, size_t &outLen) {
  constexpr uint8_t VERSION = 1;

  out[0] = VERSION;
  out[1] = DEVICE_ID;
  encodeU32BE(&out[2], sample.timestamp);
  encodeS16BE(&out[6], sample.temperatureCx100);
  encodeU16BE(&out[8], sample.humidityPctx100);
  encodeU16BE(&out[10], sample.co2ppm);
  encodeU16BE(&out[12], sample.pressureDeciHpa);
  encodeU16BE(&out[14], sample.vocRaw);
  encodeU16BE(&out[16], sample.smokeRaw);
  out[18] = sample.statusFlags;

  const size_t payloadLen = 19;
  uint32_t crc = crc32(out, payloadLen);
  encodeU32BE(&out[19], crc);
  outLen = payloadLen + 4;
  return crc;
}

static void logSample(const Sample &sample) {
  Serial.print(F("t="));
  Serial.print(sample.timestamp);
  Serial.print(F("s, temp="));
  Serial.print(sample.temperatureCx100 / 100.0f);
  Serial.print(F("C, hum="));
  Serial.print(sample.humidityPctx100 / 100.0f);
  Serial.print(F("%, co2="));
  Serial.print(sample.co2ppm);
  Serial.print(F("ppm, pressure="));
  Serial.print(sample.pressureDeciHpa / 10.0f);
  Serial.print(F(" hPa, voc="));
  Serial.print(sample.vocRaw);
  Serial.print(F(", smoke="));
  Serial.print(sample.smokeRaw);
  Serial.print(F(", flags=0x"));
  Serial.println(sample.statusFlags, HEX);
}

static void pollLoRaReceive() {
  if (!loraReady) return;

  for (;;) {
    String line;
    if (!radio.readLine(line, 200)) break;
    line.trim();
    if (line.length() == 0) continue;
    bool isRxLine = line.startsWith("+TEST: RXLRPKT") || line.startsWith("+TEST: RX \"");
    if (!isRxLine) {
      Serial.print(F("[LoRa] unsolicited: "));
      Serial.println(line);
      continue;
    }

    int quoteStart = line.indexOf('"');
    int quoteEnd = line.lastIndexOf('"');
    String hexPayload;
    if (quoteStart >= 0 && quoteEnd > quoteStart) {
      hexPayload = line.substring(quoteStart + 1, quoteEnd);
    } else {
      int comma = line.lastIndexOf(',');
      if (comma >= 0 && comma + 1 < line.length()) {
        hexPayload = line.substring(comma + 1);
      } else {
        continue;
      }
    }
    hexPayload.trim();

    uint8_t buf[32] = {};
    size_t decoded = 0;
    if (!decodeHex(hexPayload, buf, sizeof(buf), decoded)) {
      Serial.println(F("[RX] unable to decode payload hex"));
      continue;
    }
    if (decoded < 23) {
      Serial.print(F("[RX] payload too short: "));
      Serial.println(decoded);
      continue;
    }

    uint32_t crcRx = (static_cast<uint32_t>(buf[19]) << 24) |
                     (static_cast<uint32_t>(buf[20]) << 16) |
                     (static_cast<uint32_t>(buf[21]) << 8) |
                     static_cast<uint32_t>(buf[22]);
    if (crcRx != crc32(buf, 19)) {
      Serial.println(F("[RX] CRC mismatch"));
      continue;
    }
    if (hasSeenCrc(crcRx)) {
      if (LORA_DEBUG) Serial.println(F("[RX] duplicate packet, skipping"));
      continue;
    }
    rememberCrc(crcRx);

    uint8_t version = buf[0];
    uint8_t nodeId = buf[1];
    uint32_t ts = (static_cast<uint32_t>(buf[2]) << 24) |
                  (static_cast<uint32_t>(buf[3]) << 16) |
                  (static_cast<uint32_t>(buf[4]) << 8) |
                  static_cast<uint32_t>(buf[5]);
    uint16_t tempCx100 = (static_cast<uint16_t>(buf[6]) << 8) | buf[7];
    uint16_t humidity = (static_cast<uint16_t>(buf[8]) << 8) | buf[9];
    uint16_t co2 = (static_cast<uint16_t>(buf[10]) << 8) | buf[11];
    uint16_t pressure = (static_cast<uint16_t>(buf[12]) << 8) | buf[13];
    uint16_t voc = (static_cast<uint16_t>(buf[14]) << 8) | buf[15];
    uint16_t smoke = (static_cast<uint16_t>(buf[16]) << 8) | buf[17];
    uint8_t flags = buf[18];

    Serial.print(F("DATA "));
    Serial.print(nodeId);
    Serial.print(' ');
    Serial.print(version);
    Serial.print(' ');
    Serial.print(ts);
    Serial.print(' ');
    Serial.print(static_cast<int16_t>(tempCx100));
    Serial.print(' ');
    Serial.print(humidity);
    Serial.print(' ');
    Serial.print(co2);
    Serial.print(' ');
    Serial.print(pressure);
    Serial.print(' ');
    Serial.print(voc);
    Serial.print(' ');
    Serial.print(smoke);
    Serial.print(' ');
    Serial.println(flags);

    Serial.print(F("[RX] node="));
    Serial.print(nodeId);
    Serial.print(F(", ver="));
    Serial.print(version);
    Serial.print(F(", ts="));
    Serial.print(ts);
    Serial.print(F("s, temp="));
    Serial.print(static_cast<int16_t>(tempCx100) / 100.0f);
    Serial.print(F("C, hum="));
    Serial.print(humidity / 100.0f);
    Serial.print(F("%, co2="));
    Serial.print(co2);
    Serial.print(F("ppm, pressure="));
    Serial.print(pressure / 10.0f);
    Serial.print(F(" hPa, voc="));
    Serial.print(voc);
    Serial.print(F(", smoke="));
    Serial.print(smoke);
    Serial.print(F(", flags=0x"));
    Serial.println(flags, HEX);

    if (!BASE_STATION_MODE && nodeId != DEVICE_ID) {
      Serial.print(F("[FWD] payload="));
      Serial.println(hexPayload);
      if (!LoRaE5::p2pTxHex(radio, hexPayload)) {
        Serial.println(F("[WARN] Forward TX failed"));
      }
    }

    sendATDebug(String(F("AT+TEST=RXLRPKT")), "+TEST: RXLRPKT", 500);
  }
}

// ----- Arduino entry points ------------------------------------------------

void setup() {
  pinMode(LED_BUILTIN, OUTPUT);
  analogReadResolution(12);
  Serial.begin(115200);
  while (!Serial && millis() < 2000) {
    ; // wait for host
  }

  if (!BASE_STATION_MODE) {
    pinMode(VOC_PIN, INPUT);
    pinMode(SMOKE_PIN, INPUT);
    I2C::begin();
    sensorsBegin();
  }

  Serial1.begin(9600);
  loraReady = configureLoRa();
  if (!loraReady) {
    Serial.println(F("[WARN] LoRa configuration failed; will keep retrying on send."));
  } else {
    Serial.println(F("[INFO] LoRa ready."));
  }
}

void loop() {
  pollLoRaReceive();

  if (BASE_STATION_MODE) {
    delay(5);  // small idle delay
    return;
  }

  static uint32_t lastSendMs = 0;
  const uint32_t now = millis();
  if (now - lastSendMs < SAMPLE_INTERVAL_MS) {
    delay(5);
    return;
  }
  lastSendMs = now;

  Sample sample = collectSample(now);
  logSample(sample);

  uint8_t packet[23] = {};
  size_t packetLen = 0;
  uint32_t crc = buildPacket(sample, packet, packetLen);
  rememberCrc(crc);

  if (!loraReady) {
    loraReady = configureLoRa();
  }

  if (loraReady) {
    String hex = toHex(packet, packetLen);
    if (LORA_DEBUG) {
      Serial.print(F("[TX] payload="));
      Serial.println(hex);
    }
    if (!LoRaE5::p2pTxHex(radio, hex)) {
      Serial.println(F("[WARN] LoRa TX failed; will retry next interval."));
      loraReady = false;
    } else {
      digitalWrite(LED_BUILTIN, HIGH);
      delay(50);
      digitalWrite(LED_BUILTIN, LOW);
    }
    sendATDebug(String(F("AT+TEST=RXLRPKT")), "+TEST: RXLRPKT", 500);
  }
}

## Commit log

2025-10-08 Added Pressure sensor adaptor board files under PCB_And_Schematics/Pressure_Sensor
    [Pressure_Sesnor_Board.kicad_pcb, Pressure_Sesnor_Board.kicad_sch]
2025-10-09 Fixed spelling.
    [Pressure_Sensor_Board.kicad_pcb, Pressure_Sensor_Board.kicad_sch]
2025-11-05 Final working LoRa code, updated case files, documentation.
    [FireLordCase.3mf, FireLordCase.f3d, FireLordCase.step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]
2025-11-17 Device PCB
    [FireLord_Device.kicad_pcb, FireLord_Device.kicad_sch, FireLord_Sensor_Device.kicad_pcb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]
2025-12-01 Arduino file must be withint subdirectory.
2025-12-03 Sensor logic is now disabled in base station mode (assumes no sensors are connected).
